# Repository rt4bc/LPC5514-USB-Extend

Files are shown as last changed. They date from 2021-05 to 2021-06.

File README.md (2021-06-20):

# LPC5514-USB-Extend
## Function
Create a board which integrated with CMSIS DAP interface for cortex MCU debugging, and extend with common digital interface, like I2C, SPI, UART, CAN, ADC, and GPIO(Including normal input and output function, also can working at bitbang mode, like FT232H chip).

## Hardware Architecture
### USB0/1 Interface
1. USB0, Full speed interface, reserved.
2. USB1, High speed interface, Custom HID device, for CMSIS-Dap interface and other extened interfaces, SPI, UART, I2C and CAN FD.
### 3D Layout
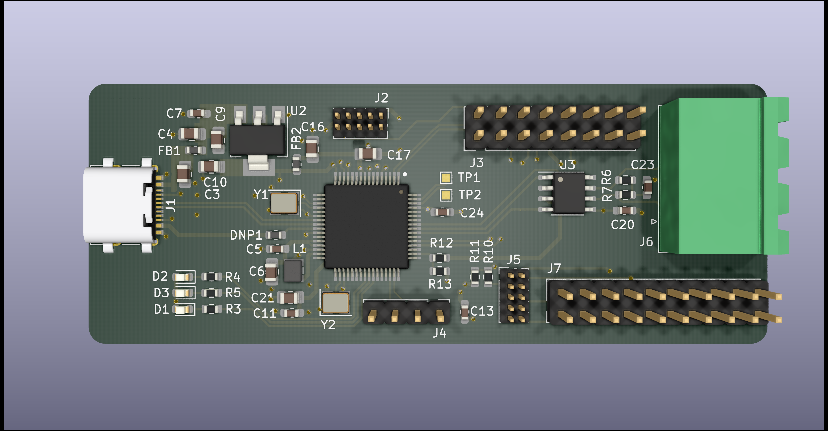
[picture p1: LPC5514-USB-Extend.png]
PCB 3D Layout


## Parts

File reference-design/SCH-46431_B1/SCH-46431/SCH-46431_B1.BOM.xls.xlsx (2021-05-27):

LPC55S16-EVK Revised: Friday, February 07, 2020
SCH-46431 PDF: SPF-46431 Revision: B1
NXP Semiconductors
6501 William Cannon Drive West
Austin, TX 78735-8598
Bill Of Materials March 9,2020 16:44:57 | Page1
Item | Agile_PN | Quantity | Reference | Value | MFG_NAME01 | Description | MFG_PN01 | Tolerance | Assy_Opt
______________________________________________
1 | 150-79475 | 13 | C1,C6,C8,C9,C10,C11,C13, | 2.2UF | AVX | CAP CER 2.2UF 10V 10% X5R 0402 | 0402ZD225KAT2A | 10%
 |  |  | C15,C16,C17,C49,C50,C53
2 | 150-79667 | 14 | C2,C4,C27,C38,C39,C41, | 4.7UF | MURATA | CAP CER 4.7uF 10V 20% X5R 0402_WIDE | GRM155R61A475MEAA | 20%
 |  |  | C42,C43,C44,C57,C59,C75,
 |  |  | C439,C446
3 | 150-75182 | 55 | C3,C5,C14,C18,C22,C23, | 0.1UF | AVX | CAP CER 0.1UF 16V 10% X7R 0402 | 0402YC104KAT2A | 10%
 |  |  | C24,C28,C29,C30,C31,C35,
 |  |  | C36,C40,C47,C48,C58,C60,
 |  |  | C69,C70,C71,C72,C73,C74,
 |  |  | C76,C77,C81,C82,C83,C84,
 |  |  | C85,C86,C87,C88,C90,C91,
 |  |  | C92,C93,C94,C95,C96,C97,
 |  |  | C440,C441,C442,C443,C444,
 |  |  | C445,C450,C451,C452,C453,
 |  |  | C454,C457,C460
4 | 150-79255 | 6 | C7,C12,C55,C56,C78,C89 | 10uF | NIC COMPONENTS CORP | CAP CER 10uF 10V 20% X5R 0402_WIDE | NMC0402X5R106M10TRPF | 20%
5 | 150-75772 | 1 | C19 | 1.0UF | YAGEO AMERICA | CAP CER 1.0UF 10V 10% X5R 0402 | CC0402KRX5R6BB105 |  | DNP
6 | 150-30082 | 5 | C21,C32,C33,C34,C98 | 0.01UF | AVX | CAP CER 0.01UF 16V 20% X7R 0402 | 0402YC103MAT2A | 20%
7 | 150-79040 | 1 | C25 | 1000pF | MURATA | CAP CER 1000pF 50V 10% X7R AEC-Q200 0402 | GCM155R71H102KA37D | 10%
8 | 150-75772 | 4 | C37,C447,C448,C449 | 1.0UF | YAGEO AMERICA | CAP CER 1.0UF 10V 10% X5R 0402 | CC0402KRX5R6BB105
9 | 150-30297 | 4 | C45,C46,C51,C52 | 220PF | KEMET | CAP CER 220PF 50V 5% C0G 0402 | C0402C221J5GAC | 5%
10 | 150-30109 | 2 | C79,C80 | 27PF | KEMET | CAP CER 27PF 50V 5% C0G 0402 | C0402C270J5GAC | 5%
11 | 150-75268 | 1 | C458 | 47PF | AVX | CAP CER 47PF 16V 5% C0G 0402 | 0402YA470JAT2A | 5%
12 | 150-78467 | 2 | C459,C461 | 22UF | SAMSUNG | CAP CER 22UF 6.3V 20% X5R 0603 | CL10A226MQ8NRNE | 20%
13 | 150-30180 | 4 | C462,C463,C464,C465 | 12PF | KEMET | CAP CER 12PF 25V 5% C0G 0402 | C0402C120J3GAC7867 | 5% | DNP
14 | 480-79840 | 2 | D1,D2 | PMEG4010CPA | NEXPERIA | DIODE ARRAY SCH RECT 1A 40V 3HUSON | PMEG4010CPA,115
15 | 480-78491 | 1 | D3 | PESD1CAN | NEXPERIA | DIODE BIDIR CAN BUS ESD PROTECTION 200W 24V AEC-Q101 SOT23 | PESD1CAN,215
16 | 370-76772 | 1 | D4 | OVSARGB4R8 | TT ELECTRONICS PLC | LED RGB MULTI 20MA SMT | OVSARGB4R8
17 | 370-76568 | 2 | D5,D8 | RED | OSRAM | LED RED SGL 20MA SMT | LS L29K-H1J2-1
18 | 480-79839 | 2 | D6,D7 | PESD5V0S2BT | NEXPERIA | DIODE TVS 5VWM 14VC SOT23 | PESD5V0S2BT,215
19 | 480-78720 | 1 | D9 | PMEG1020EH | NEXPERIA | DIODE SCH RECT 10V 2A SOD123F | PMEG1020EH,115
20 | 480-79814 | 2 | D10,D12 | PESD3V3S1UB | NEXPERIA | DIODE TVS UNIDIR 3.3VWM 20VC SOD523 | PESD3V3S1UB,115
21 | 480-79841 | 1 | D11 | PESD3V3L5UY | NEXPERIA | DIODE TVS UNIDIR 3.3VWM 12VC SOT363 | PESD3V3L5UY,115
22 | 180-78156 | 9 | L1,FB1,L2,FB2,L3,L4,L5, | 330 OHM | TDK | IND FER BEAD 330OHM@100MHZ 1.7A 0603 | MPZ1608S331A | 25%
 |  |  | L6,L7
23 | 210-81491 | 4 | JP1,JP2,JP3,JP8 | HDR_1X3 | ANYTRONIC CORPORATION LIMITED | HDR 1X3 TH 100MIL SP 338H AU 98L | 0901S0203011N9T-31RF
24 | 210-81491 | 2 | JP4,JP5 | HDR_1X3 | ANYTRONIC CORPORATION LIMITED | HDR 1X3 TH 100MIL SP 338H AU 98L | 0901S0203011N9T-31RF |  | DNP
25 | 210-81490 | 20 | JS2,JS3,JS4,JS5,JP6,JP7, | HDR 1X2 | ANYTRONIC CORPORATION LIMITED | HDR 1X2 TH 100MIL SP 339H AU 98L | 0901S0202011N9T-31RF
 |  |  | JP9,JP12,JP13,JP14,JP15,
 |  |  | JP16,JP17,JP18,JP19,JP20,
 |  |  | JP21,JP22,JP23,JP24
26 | 210-81490 | 1 | JS1 | HDR 1X2 | ANYTRONIC CORPORATION LIMITED | HDR 1X2 TH 100MIL SP 339H AU 98L | 0901S0202011N9T-31RF |  | DNP
27 | 210-82071 | 2 | J1,J2 | ZX62D-B-5PA8(30) | HIROSE | CON 5 MICRO USB_TYPE_B 2.0 RA SMT SKT TH 0.65MM SP 104H AU | ZX62D-B-5PA8(30)
28 | 211-78692 | 2 | J3,J4 | USB AB 5 | HIROSE | CON 5 USB MICRO-AB RA SKT SMT 0.65MM SP AU | ZX62D-AB-5P8(30)
29 | 211-79155 | 2 | J5,J6 | SJ-3524-SMT | CUI Inc | CON 4 AUD JACK 3.5MM SMT -- 211H AG | SJ-3524-SMT
30 | 210-78679 | 2 | J7,J8 | CON SKT 8 | SULLINS ELECTRONICS CORP | CON 1X8 SKT SHRD TH 100MIL SP 335H AU 126L | PPPC081LFBN-RC
31 | 210-79497 | 3 | J9,J10,J12 | CON_2X10 | WURTH ELEKTRONIK EISOS GMBH & CO. KG (ELECTRONIC & ELECTROMEHANICAL COMP) | CON 2X10 SKT TH 100MIL CTR 343H AU 122L | 61302021821
32 | 210-81920 | 1 | J11 | HDR 1X4 | WURTH ELEKTRONIK EISOS GMBH & CO. KG (ELECTRONIC & ELECTROMEHANICAL COMP) | HDR 1X4 TH 2.54MM SP 344H AU 118L | 61300411121
33 | 210-81685 | 1 | J13 | SKT_2X6 | WURTH ELEKTRONIK EISOS GMBH & CO. KG (ELECTRONIC & ELECTROMEHANICAL COMP) | CON 2X6 SKT TH 2.54MM CTR 339H AU 122L | 61301221821
34 | 210-81466 | 1 | J16 | HDR 2X5 | ANYTRONIC CORPORATION LIMITED | HDR 2X5 TH 50MIL CTR 172H AU 91L | 0922S0205011N9T-31RF |  | DNP
35 | 210-81466 | 1 | J17 | HDR 2X5 | ANYTRONIC CORPORATION LIMITED | HDR 2X5 TH 50MIL CTR 172H AU 91L | 0922S0205011N9T-31RF
36 | 210-80998 | 1 | J18 | PPPC062LJBN-RC | SULLINS ELECTRONICS CORP | CON 2X6 SKT RA TH 100MIL CTR 206H AU 124L | PPPC062LJBN-RC
37 | 210-82038 | 1 | J19 | DB9 | REGAL ELECTRONICS | CON 9 DB MALE 0.318 PLUG RA SHLD TH 109MIL SP 500H -- 145L | R4019-09BT
38 | 211-76501 | 2 | J20,J21 | CONN USB_TYPE_A 4 | SAMTEC | CON 4 USB_TYPE_A RA SKT SMT -- 264H AU | USB-A-S-S-B-SM2 |  | DNP
39 | 210-79790 | 8 | J22,J23,J24,J25,J26,J27, | HDR_1X1 | SAMTEC | HDR 1X1 TH -- 350H AU 100L | TSW-101-07-L-S
 |  |  | J28,J29
40 | 180-78469 | 3 | L8,L9,L10 | 600OHM | WURTH ELEKTRONIK EISOS GMBH & CO. KG (ELECTRONIC & ELECTROMEHANICAL COMP) | IND FER BEAD 600OHM@100MHz 1A 25% 0603 | 742792651 | +/-25%
41 | 180-78872 | 1 | L11 | 4.7uH | BOURNS | IND PWR SHIELDED 4.7uH@1MHZ 1.55A 20% AEC-Q200 SMD | SRP2512A-4R7M | 20%
42 | 480-79842 | 1 | Q1 | BSS138P | NEXPERIA | TRAN NMOS 60V 360MA AEC-Q101 TO-236AB | BSS138P,215
43 | 480-79619 | 2 | Q4,Q5 | PMDXB600UNEZ | NEXPERIA | TRAN NMOS PWR SW 600mA 20V 620mOHM DFN1010B-6 | PMDXB600UNEZ
44 | 470-81849 | 42 | R1,R2,R3,R4,R6,R13,R15, | 0 | STACKPOLE ELECTRONICS | RES MF ZERO OHM 1/16W -- AEC-Q200 0402 | RMCF0402ZT0R00
 |  |  | R24,R26,R60,R61,R62,R64,
 |  |  | R65,R70,R71,R72,R73,R76,
 |  |  | R77,R78,R79,R80,R81,R82,
 |  |  | R83,R84,R85,R86,R87,R88,
 |  |  | R89,R90,R93,R104,R130,
 |  |  | R131,R137,R152,R153,R154,
 |  |  | R166
45 | 470-81849 | 7 | R5,R14,R63,R114,R119, | 0 | STACKPOLE ELECTRONICS | RES MF ZERO OHM 1/16W -- AEC-Q200 0402 | RMCF0402ZT0R00 |  | DNP
 |  |  | R136,R151
46 | 470-76240 | 19 | R7,R8,R9,R10,R11,R19,R28, | 100K | NIC COMPONENTS CORP | RES MF 100K 1/16W 1% 0402 | NRCL04F1003TRF | 1%
 |  |  | R44,R45,R97,R113,R116,
 |  |  | R117,R122,R126,R147,R160,
 |  |  | R163,R165
47 | 470-82125 | 6 | R12,R46,R47,R48,R150, | 1K | NIC COMPONENTS CORP | RES MF 1.0K 1/16W 5% 0402 | NRCL04J102TRF | 5%
 |  |  | R158
48 | 470-75557 | 3 | R20,R66,R129 | 10K | VISHAY INTERTECHNOLOGY | RES MF 10K 1/16W 5% 0402 | CRCW040210K0JNED | 5%
49 | 470-81807 | 2 | R21,R27 | 60.4 | VISHAY INTERTECHNOLOGY | RES MF 60.4 OHM 1/10W 1% AEC-Q200 0603 | CRCW060360R4FKEA
50 | 470-75591 | 19 | R23,R25,R36,R111,R112, | 100 | NIC COMPONENTS CORP | RES MF 100 OHM 1/16W 5% 0402 | NRCL04J101TRF | 5%
 |  |  | R118,R123,R127,R138,R139,
 |  |  | R140,R141,R142,R143,R144,
 |  |  | R145,R161,R162,R164
51 | 470-78359 | 26 | R29,R39,R40,R42,R74,R75, | 2.2K | WALSIN TECHNOLOGY CORP. | RES MF 2.2K 1/16W 1% 0402 | WR04X2201FTL | 1%
 |  |  | R99,R100,R101,R102,R105,
 |  |  | R106,R110,R120,R121,R124,
 |  |  | R125,R128,R132,R133,R134,
 |  |  | R135,R146,R148,R149,R159
52 | 470-76237 | 3 | R30,R37,R38 | 510 | YAGEO AMERICA | RES 510 OHMS 1/16W 5% RC0402 ROHS | RC0402JR-07510RL
53 | 470-77301 | 1 | R31 | 680 | PANASONIC | RES MF 680 OHM 1/16W 5% 0402 | ERJ-2GEJ681X | 5%
54 | 470-75557 | 4 | R32,R33,R34,R35 | 10K | VISHAY INTERTECHNOLOGY | RES MF 10K 1/16W 5% 0402 | CRCW040210K0JNED | 5% | DNP
55 | 470-79978 | 1 | R41 | 1M | KOA SPEER | RES MF 1M 1/10W 5% AEC-Q200 0402 | RK73B1ETTP105J | 5%
56 | 470-81808 | 1 | R43 | 330K | KOA SPEER | RES MF 330K 1/10W 1% AEC-Q200 0402 | RK73H1ETTP3303F | 1%
57 | 470-31023 | 2 | R49,R50 | 47K | YAGEO AMERICA | RES MF 47K 1/16W 1% 0402 | RC0402FR-0747KL | 1%
58 | 470-80286 | 2 | R51,R52 | 20 | Panasonic | RES MF 20 OHM 1/10W 1% 0402 | ERJ2RKF20R0X | 1%
59 | 470-76103 | 1 | R67 | 20K | WALSIN TECHNOLOGY CORP. | RES MF 20K 1/16W 1% 0402 | WR04X2002FTL | 1%
60 | 470-78359 | 5 | R91,R92,R107,R108,R109 | 2.2K | WALSIN TECHNOLOGY CORP. | RES MF 2.2K 1/16W 1% 0402 | WR04X2201FTL | 1% | DNP
61 | 470-76469 | 1 | R94 | 470 | THYE MING TECH CO LTD | RES MF 470 OHM 1/16W 1% 0402 | CR-02FL6--470R | 1%
62 | 470-76098 | 3 | R95,R96,R98 | 12.1K | BOURNS | RES MF 12.1K 1/16W 1% 0402 | CR0402-FX-1212GLF | 1%
63 | 470-76303 | 1 | R103 | 1.5K | VISHAY INTERTECHNOLOGY | RES MF 1.5K 1/16W 5% 0402 | CRCW04021K50JNED | 5%
64 | 470-76240 | 1 | R115 | 100K | NIC COMPONENTS CORP | RES MF 100K 1/16W 1% 0402 | NRCL04F1003TRF | 1% | DNP
65 | 470-80217 | 2 | R155,R156 | 0 | MULTICOMP | RES MF ZERO OHM 1/10W 1% 0603 | MC0603SAF0000T5E | 1%
66 | 280-76498 | 4 | SS1,SS2,SS3,SS4 | .635" LONG | UNICORP | FASTENER, STANDOFF 4.5MMX3.53XM3.0X0.5 ROUND THR .635"L BRASS | MSS251-R-1-A-16 |  | DNP
67 | 510-78172 | 4 | SW1,SW2,SW3,SW4 | KMR221NG LFS | C&K COMPONENTS | SW SPST MOM PB NO 50MA 32V SMT | KMR221NG LFS
68 | 510-78183 | 4 | TP1,TP2,TP3,TP4 | TP_2P7X4P7 | NA | TEST POINT RECT 2P7X4P7 MM NO PART TO ORDER | NO PART TO ORDER1
69 | 510-75618 | 5 | TP5,TP6,TP7,TP8,TP9 | TP_35MIL |  | TEST POINT PAD .035 SMT, no part to order
70 | 211-76644 | 1 | TP10 | TPAD_050 | NOTACOMPONENT | TEST POINT PAD 50MIL DIA SMT, NO PART TO ORDER | NOTACOMPONENT
71 | 315-80698 | 1 | U1 | NCP1117ST25T3G | ON Semiconductor | IC VREG LDO 2.5V 1A 20V SOT-223 | NCP1117ST25T3G
72 | 480-78843 | 3 | U2,U6,U8 | RClamp0854P.TCT | SEMTECH CORP | DIODE TVS ARRAY 3 5.5V SLP1616P6 | RClamp0854P.TCT
73 | 315-79987 | 1 | U3 | NCP692MN33T2G | ON SEMICONDUCTOR | IC VREG LDO 3.3V 1A 6V DFN6 | NCP692MN33T2G
74 | 315-80443 | 1 | U4 | NCP692MN18T2G | ON SEMICONDUCTOR | IC LIN VREG CMOS VLDO W/EN 1.8V 1A 1.5-6V DFN6 | NCP692MN18T2G
75 | 315-81532 | 1 | U5 | NX3L2267GM,115 | NXP SEMICONDUCTORS | IC ANALOG SW DUAL SPDT 1.4-4.3V XQFN10 | NX3L2267GM,115
76 | 312-81574 | 1 | U7 | NX5P3090UK | NXP SEMICONDUCTORS | IC USB PD TYPE C CURRENT LIMITED PWR SW 2.5-5.5V WLCSP12 | NX5P3090UK,012
77 | 312-81317 | 1 | U9 | TJA1044GT | NXP SEMICONDUCTORS | IC XCVR CAN HS 4.75-5.25V AEC-Q100 SO8 | TJA1044GTJ
78 | 312-81329 | 3 | U11,U22,U24 | 74AVC4TD245BQ | NEXPERIA | IC DUAL SUPPLY XCVR XLTR 4BIT 0-3.6V DHVQFN16 | 74AVC4TD245BQ,115
79 | 312-80418 | 1 | U12 | FXOS8700CQ | FREESCALE SEMICONDUCTOR | IC ACCELEROMETER AND MAGNETOMETER SENSOR 3-AXIS 2.5V QFN16 | FXOS8700CQ
80 | 315-81538 | 1 | U13 | WM8904 | CIRRUS LOGIC | IC AUDIO ULTRA LOW POWER CODEC 1V QFN32 | WM8904CGEFL/V
81 | 344-02176 | 1 | U16 | LPC4322JET100 | NXP SEMICONDUCTORS | IC MCU CORTEX M4 CORE 512kB FLASH 2.4-3.6V BGA100 | LPC4322JET100E
82 | 312-80487 | 1 | U17 | 74AVC2T45DP | NEXPERIA | IC XCVR 0.8-3.6V/0.8-3.6V TSSOP8 | 74AVC2T45DP,125
83 | 315-80822 | 1 | U18 | NX3DV2567GU | NXP SEMICONDUCTORS | IC LIN SW 4PDT 1.4-4.3V XQFN16 | NX3DV2567GU,115
84 | 312-81277 | 5 | U19,U20,U21,U25,U26 | 74LVC1T45GW,125 | NEXPERIA | IC XCVR XLATING DUAL 3-STATE 1.2- 5.5V TSSOP6 | 74LVC1T45GW,125
85 | 312-82179 | 1 | U23 | 74LVC1G07GW-Q100 | NEXPERIA | IC BUF NON-INV SGL 1.65-5.5V AEC-Q100 TSSOP5 | 74LVC1G07GW-Q100H
86 | TMP-WF-36553 | 1 | U27 | LPC55S16JBD100 | NXP SEMICONDUCTORS | IC MCU 32BIT ARM CORTEX-M33 FLASH 256KB SRAM 96KB 1.8-3.6V HLQFP100 | LPC55S16JBD100
87 | 230-78082 | 1 | Y1 | 12MHZ | ABRACON CORP | XTAL 12MHZ RSN -- 18PF 30PPM SMT | ABLS2-12.000MHZ-D4Y-T
88 | 230-78034 | 1 | Y2 | 16MHZ | KYOCERA | XTAL 16MHZ 8PF AEC-Q200 SMD | CX3225SA16000D0PTW
89 | 230-78102 | 1 | Y3 | 32.768KHZ | EPSON ELECTRONICS | XTAL 32.768KHZ 7PF 20PPM -- SMT | FC-135 32.7680KA-AG3

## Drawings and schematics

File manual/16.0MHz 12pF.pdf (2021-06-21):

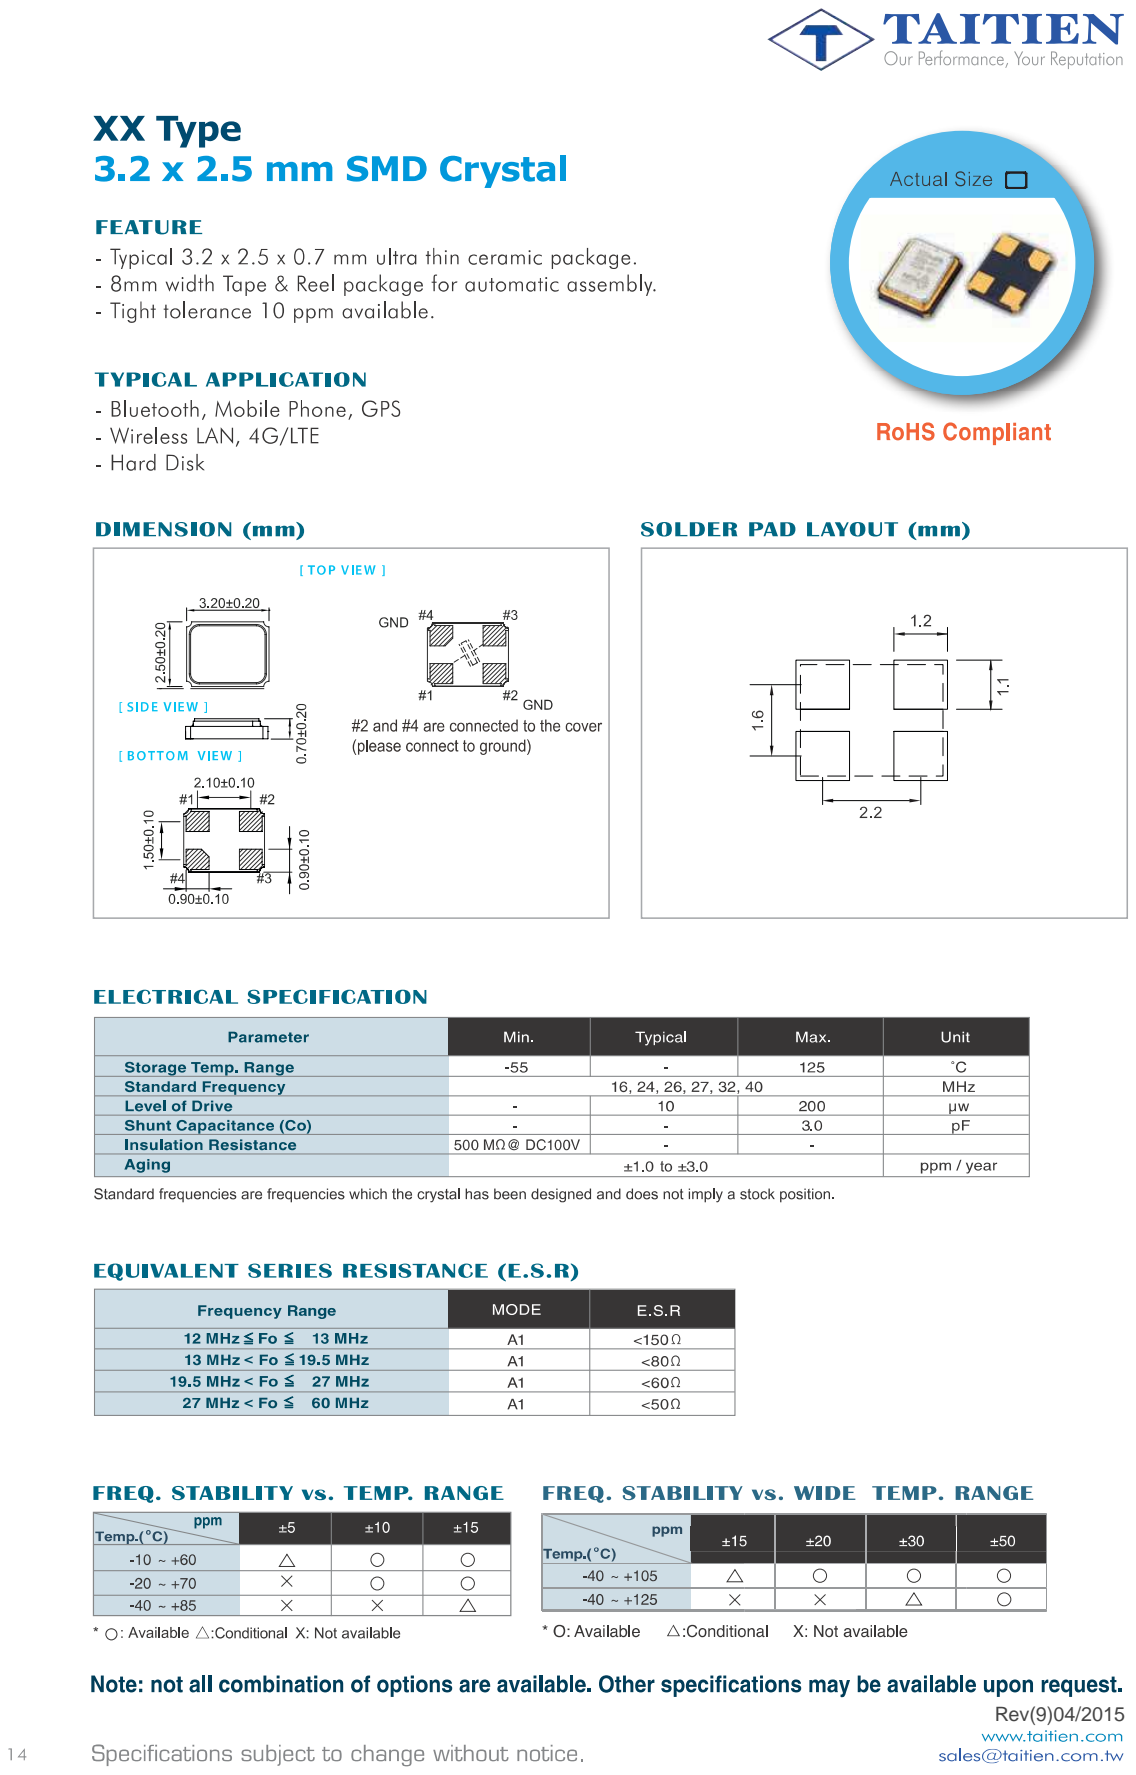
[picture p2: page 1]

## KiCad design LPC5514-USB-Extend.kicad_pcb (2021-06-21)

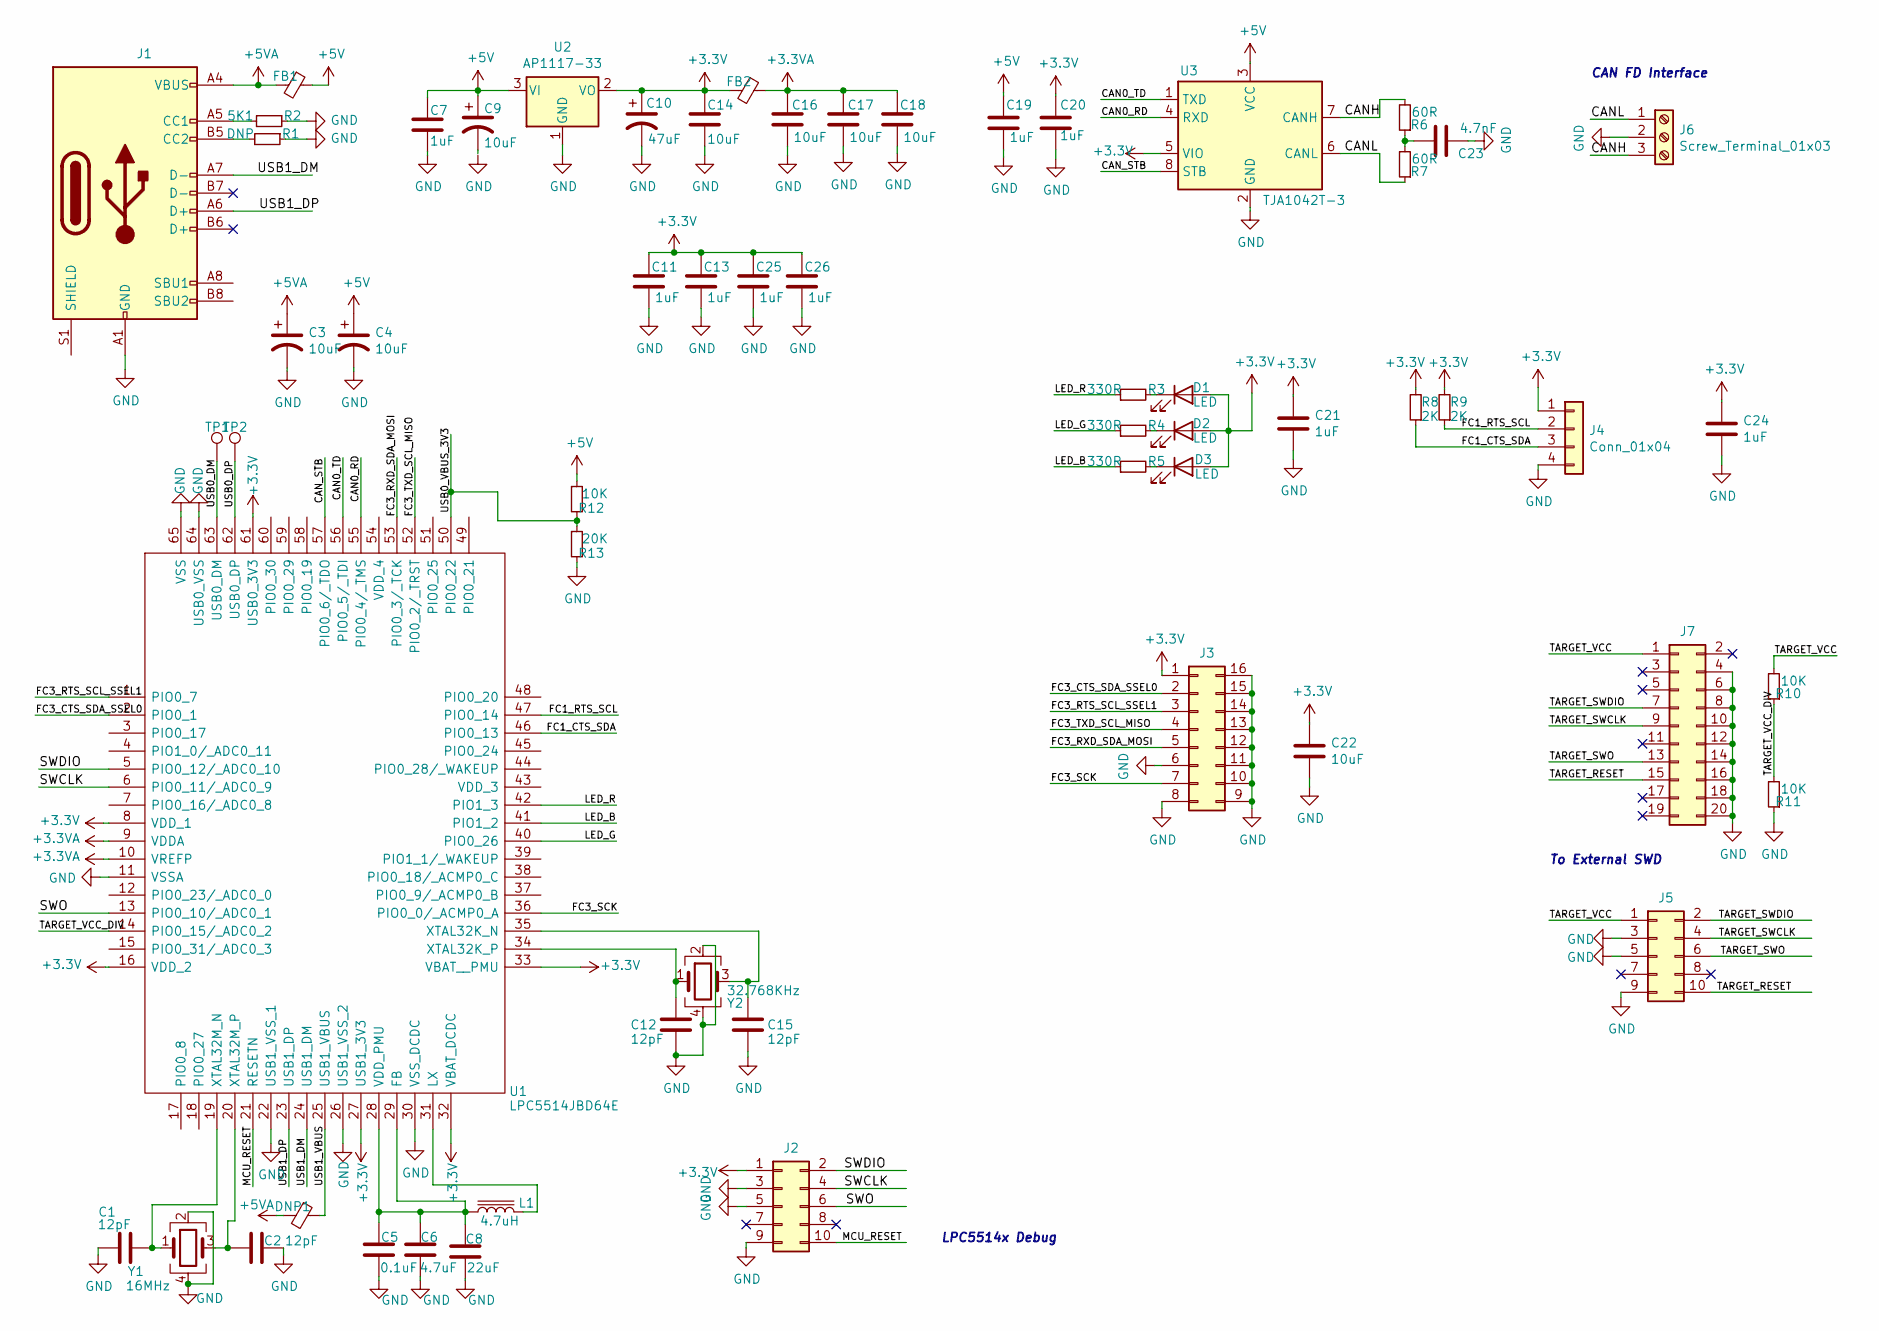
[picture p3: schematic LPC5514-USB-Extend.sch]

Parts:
C1, C2, C12, C15: 12pF; C_0603_1608Metric_Pad1.08x0.95mm_HandSolder
C3, C4, C9, C14, C16, C17, C18: 10uF; C_0805_2012Metric_Pad1.18x1.45mm_HandSolder
C5: 0.1uF; C_0603_1608Metric_Pad1.08x0.95mm_HandSolder
C6: 4.7uF; C_0805_2012Metric_Pad1.18x1.45mm_HandSolder
C7, C11, C13, C19, C20, C24, C25, C26: 1uF; C_0603_1608Metric_Pad1.08x0.95mm_HandSolder
C8: 22uF; C_0805_2012Metric_Pad1.18x1.45mm_HandSolder
C10: 47uF; C_0805_2012Metric_Pad1.18x1.45mm_HandSolder
C21: 1uF; C_0805_2012Metric_Pad1.18x1.45mm_HandSolder
C22: 10uF; C_0603_1608Metric_Pad1.08x0.95mm_HandSolder
C23: 4.7nF; C_0603_1608Metric_Pad1.08x0.95mm_HandSolder
D1, D2, D3: LED; LED_0603_1608Metric
DNP1: Ferrite_Bead_Small; L_0603_1608Metric
FB1, FB2: Ferrite_Bead_Small; L_0603_1608Metric
J1: USB_C_Receptacle_USB2.0; USB_C_Receptacle_HRO_TYPE-C-31-M-12
J2, J5: Conn_02x05_Odd_Even; PinHeader_2x05_P1.27mm_Vertical
J3: Conn_02x08_Counter_Clockwise; PinHeader_2x08_P2.54mm_Vertical
J4: Conn_01x04; PinHeader_1x04_P2.54mm_Vertical
J6: Screw_Terminal_01x03; PhoenixContact_MSTBA_2,5_3-G-5,08_1x03_P5.08mm_Horizontal
J7: Conn_02x10_Odd_Even; PinHeader_2x10_P2.54mm_Vertical
L1: 4.7uH; L_Wuerth_MAPI-2512
R1: DNP; R_0603_1608Metric
R2: 5K1; R_0603_1608Metric
R3, R4, R5: 330R; R_0603_1608Metric
R6, R7: 60R; R_0603_1608Metric
R8, R9: 2K; R_0603_1608Metric
R10, R11, R12: 10K; R_0603_1608Metric
R13: 20K; R_0603_1608Metric
TP1, TP2: TestPoint; TestPoint_Pad_1.0x1.0mm
U1: LPC5514JBD64E; QFP50P1200X1200X120-65N; Manufacturer_Part_Number LPC5514JBD64E; Mouser Part Number 771-LPC5514JBD64E
U2: AP1117-33; SOT-223-3_TabPin2
U3: TJA1042T-3; SOIC-8_3.9x4.9mm_P1.27mm
Y1: 16MHz; Oscillator_SMD_Abracon_ASE-4Pin_3.2x2.5mm
Y2: 32.768KHz; Oscillator_SMD_Abracon_ASE-4Pin_3.2x2.5mm

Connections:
+3.3VA: C16.1, C17.1, C18.1, FB2.1, U1.9 (VDDA), U1.10 (VREFP)
+3V3: C10.1, C11.1, C13.1, C14.1, C20.1, C21.1, C22.1, C24.1, C25.1, C26.1, D1.2 (A), D2.2 (A), D3.2 (A), FB2.2, J2.1, J3.1, J4.1, R8.2, R9.2, U1.8 (VDD_1), U1.16 (VDD_2), U1.27 (USB1_3V3), U1.32 (VBAT_DCDC), U1.33 (VBAT__PMU), U1.61 (USB0_3V3), U2.2 (VO), U3.5 (VIO)
+5V: C4.1, C7.1, C9.1, C19.1, FB1.1, R12.1, U2.3 (VI), U3.3 (VCC)
+5VA: C3.1, DNP1.2, FB1.2, J1.A4 (VBUS), J1.A9 (VBUS), J1.B4 (VBUS), J1.B9 (VBUS)
/CAN0_RD: U1.55 (PIO0_4/_TMS), U3.4 (RXD)
/CAN0_TD: U1.56 (PIO0_5/_TDI), U3.1 (TXD)
/CANH: J6.3, R6.2, U3.7 (CANH)
/CANL: J6.1, R7.1, U3.6 (CANL)
/CAN_STB: U1.57 (PIO0_6/_TDO), U3.8 (STB)
/FC1_CTS_SDA: J4.3, R8.1, U1.46 (PIO0_13)
/FC1_RTS_SCL: J4.2, R9.1, U1.47 (PIO0_14)
/FC3_CTS_SDA_SSEL0: J3.2, U1.2 (PIO0_1)
/FC3_RTS_SCL_SSEL1: J3.3, U1.1 (PIO0_7)
/FC3_RXD_SDA_MOSI: J3.5, U1.53 (PIO0_3/_TCK)
/FC3_SCK: J3.7, U1.36 (PIO0_0/_ACMP0_A)
/FC3_TXD_SCL_MISO: J3.4, U1.52 (PIO0_2/_TRST)
/LED_B: R5.1, U1.41 (PIO1_2)
/LED_G: R4.1, U1.40 (PIO0_26)
/LED_R: R3.1, U1.42 (PIO1_3)
/MCU_RESET: J2.10, U1.21 (RESETN)
/SWCLK: J2.4, U1.6 (PIO0_11/_ADC0_9)
/SWDIO: J2.2, U1.5 (PIO0_12/_ADC0_10)
/SWO: J2.6, U1.13 (PIO0_10/_ADC0_1)
/TARGET_RESET: J5.10, J7.15
/TARGET_SWCLK: J5.4, J7.9
/TARGET_SWDIO: J5.2, J7.7
/TARGET_SWO: J5.6, J7.13
/TARGET_VCC: J5.1, J7.1, R10.2
/TARGET_VCC_DIV: R10.1, R11.2, U1.14 (PIO0_15/_ADC0_2)
/USB0_DM: TP1.1, U1.63 (USB0_DM)
/USB0_DP: TP2.1, U1.62 (USB0_DP)
/USB0_VBUS_3V3: R12.2, R13.1, U1.50 (PIO0_22)
/USB1_DM: J1.A7 (D-), U1.24 (USB1_DM)
/USB1_DP: J1.A6 (D+), U1.23 (USB1_DP)
/USB1_VBUS: DNP1.1, U1.25 (USB1_VBUS)
GND: C1.2, C2.1, C3.2, C4.2, C5.1, C6.1, C7.2, C8.1, C10.2, C11.2, C12.1, C13.2, C14.2, C15.1, C16.2, C17.2, C18.2, C19.2, C20.2, C21.2, C22.2, C23.1, C24.2, C25.2, C26.2, J1.A1 (GND), J1.A12 (GND), J1.B1 (GND), J1.B12 (GND), J2.3, J2.5, J2.9, J3.6, J3.8, J3.9, J3.10, J3.11, J3.12, J3.13, J3.14, J3.15, J3.16, J4.4, J5.3, J5.5, J5.9, J6.2, J7.4, J7.6, J7.8, J7.10, J7.12, J7.14, J7.16, J7.18, J7.20, R1.1, R2.1, R11.1, R13.2, U1.11 (VSSA), U1.22 (USB1_VSS_1), U1.26 (USB1_VSS_2), U1.30 (VSS_DCDC), U1.64 (USB0_VSS), U1.65 (VSS), U2.1 (GND), U3.2 (GND), Y1.2, Y1.4, Y2.2, Y2.4
unnamed: C1.1, U1.19 (XTAL32M_N), Y1.1
unnamed: C2.2, U1.20 (XTAL32M_P), Y1.3
unnamed: C5.2, C6.2, C8.2, L1.1, U1.28 (VDD_PMU), U1.29 (FB)
unnamed: C12.2, U1.34 (XTAL32K_P), Y2.1
unnamed: C15.2, U1.35 (XTAL32K_N), Y2.3
unnamed: C23.2, R6.1, R7.2
unnamed: D1.1 (K), R3.2
unnamed: D2.1 (K), R4.2
unnamed: D3.1 (K), R5.2
unnamed: J1.A5 (CC1), R2.2
unnamed: J1.B5 (CC2), R1.2
unnamed: L1.2, U1.31 (LX)

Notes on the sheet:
To External SWD
LPC5514x Debug
CAN FD Interface

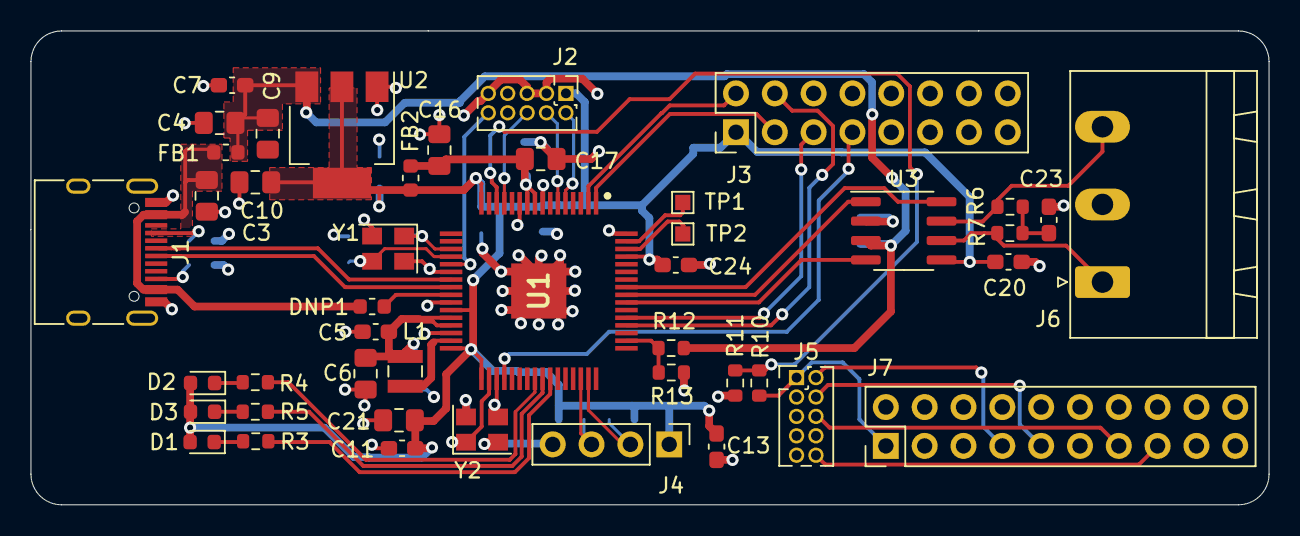
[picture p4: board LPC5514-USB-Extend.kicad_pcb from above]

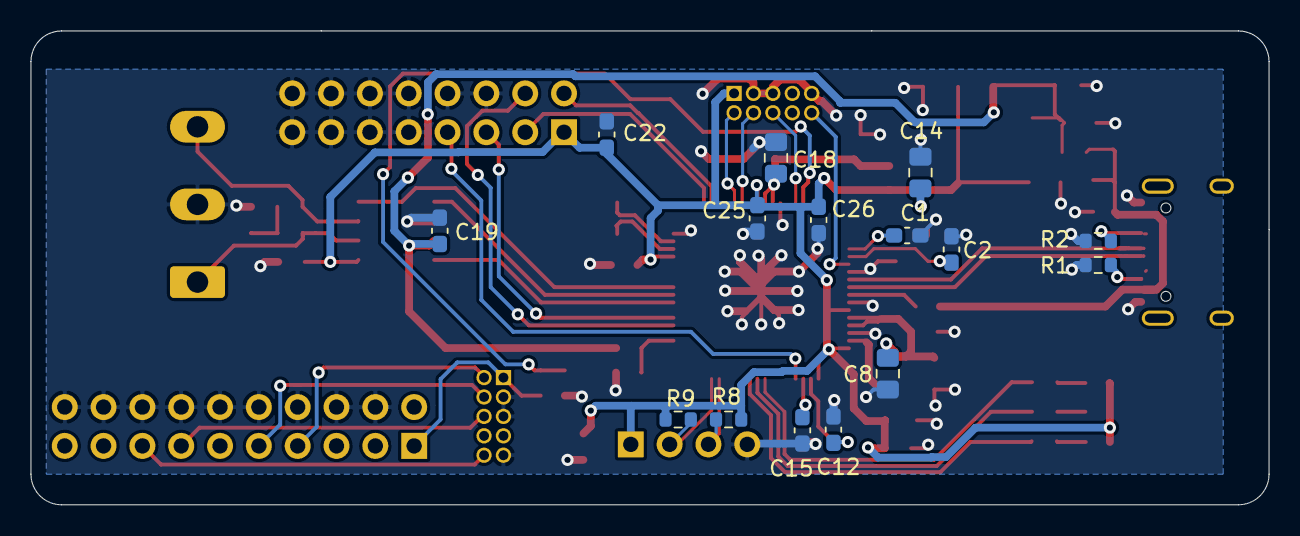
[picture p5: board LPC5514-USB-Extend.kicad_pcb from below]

Board: 2 copper layers, 81.0 x 31.0 mm, 60 parts (15 on the bottom side), 48 nets.

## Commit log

2021-06-06 update design, usb0/1 connection & power
    [LPC5514-USB-Extend.sch]
2021-06-15 update sch and add footprint
    [LPC5514-USB-Extend.kicad_pcb, LPC5514-USB-Extend.sch]
2021-06-16 update pcb
    [LPC5514-USB-Extend.kicad_pcb, LPC5514-USB-Extend.sch]
2021-06-20 update design
    [LPC5514-USB-Extend.kicad_pcb, LPC5514-USB-Extend.sch]
2021-06-20 Add PCB 3D Layout in readme file
2021-06-21 update pcb & add data manual
    [LPC5514-USB-Extend.kicad_pcb, LPC5514-USB-Extend.sch]
